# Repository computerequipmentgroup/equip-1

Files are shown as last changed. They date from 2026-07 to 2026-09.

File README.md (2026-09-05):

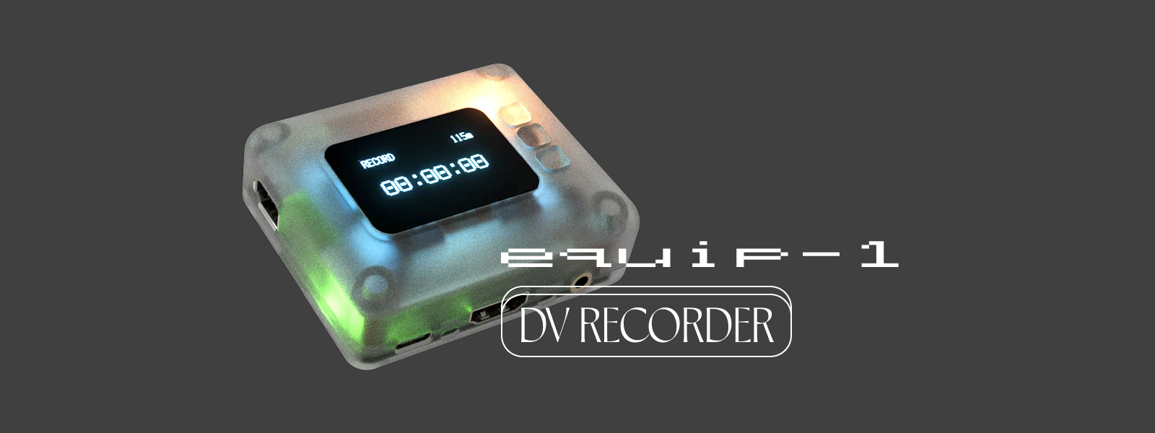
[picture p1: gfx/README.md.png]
Equip-1 DV Recorder


# Equip-1 ⚹ DV RECORDER

Equip-1 is an open-source, portable DV/HDV recorder for camcorders with FireWire/i.LINK/DV output. It is built around a Radxa ROCK 2F and a custom PCIe FireWire HAT, so you can mount it near a camera, power it from USB-C, press one button, and record tape footage directly to removable storage.

The project is for camera enthusiasts, videographers, film schools, archivists, and hardware/software contributors who want a modern, repairable path for capturing DV tapes without keeping an old laptop alive.

The [Firehat](https://github.com/computerequipmentgroup/firehat) is also available standalone. It works as a HAT for the ROCK 2F, Raspberry Pi 5, and other SBCs.

Website: <https://www.equip-1.c-e.group/>  
Community: [discord.gg/wpXmcb5mvK](https://discord.gg/wpXmcb5mvK)

## Features

- One-button DV/HDV capture from FireWire camcorders.
- On-device OLED/buttons UI + web based controls.
- Web UI controls for recording, video preview, file management and conversion settings.
- Full-quality `.mov`, `.dv`, `.avi`, or native HDV `.m2t` recordings.
- On-demand or automatic MP4 conversions for easy previewing and sharing.
- Optional MP4 deinterlacing for cleaner playback from interlaced DV sources.
- USB/SD capture storage handling, in-app updates, and HDMI preview support.

## Getting started

### 1. Download and flash a release image

The recommended way to get started is to use a prebuilt Equip-1 image from GitHub Releases.

1. Open the releases page: <https://github.com/computerequipmentgroup/equip-1/releases>
2. Download the latest image for your hardware; Equip-1 uses the Rock 2F image.
3. Install and open [balenaEtcher](https://etcher.balena.io/).
4. In Etcher, choose the Equip-1 image, choose your microSD card, then click **Flash**.
5. When flashing is complete, eject the card, insert it into Equip-1, and power the device over USB-C.

To build and flash an image from source instead:

```bash
./src/buildroot/scripts/build.sh
./src/buildroot/scripts/flash.sh
```

The default runtime settings are baked into the image from:

```text
src/buildroot/overlay/etc/equip1/equip-1.ini
```

On a running device, edit the live settings file at:

```text
/etc/equip1/equip-1.ini
```

### 2. Connect to Equip-1

Default device access:

| Setting | Default |
| --- | --- |
| Wi-Fi SSID | `Equip-1` |
| Wi-Fi password | `firesecret` |
| Dashboard | `http://10.42.0.1/` |
| API base | `http://10.42.0.1/api` |

Connect a phone or laptop to the Equip-1 Wi-Fi network, open the dashboard, attach a FireWire DV/HDV camera, and use the web UI or the device buttons to preview and record.

### 3. Prepare capture storage

Equip-1 records to `/data/captures` by default. At boot it prefers a non-root exFAT USB-A drive labelled `EQUIP1`; otherwise it falls back to the SD-card data partition. On a freshly flashed compressed image, first boot creates the missing SD-card recordings partition in the remaining free space, formats it as exFAT, labels it `EQUIP1`, and mounts it at `/data`.

Recommended capture storage format:

- filesystem: exFAT
- label: `EQUIP1`
- mount point on device: `/data`
- captures path: `/data/captures`

If automatic provisioning fails and the UI shows only rootfs-sized free space, create one exFAT partition labelled `EQUIP1` in the unallocated space after the flashed image partitions. Do not modify the boot/rootfs partitions and do not create two exFAT data partitions.

### 4. Record and export

Completed DV recordings are written as full-quality `.mov` captures by default, with settings for raw `.dv` or `.avi` containers. HDV sources still record as native `.m2t`. MP4 sidecars can be created on demand from settings, or automatically after each recording if auto-MP4 export is enabled.

MP4 quality presets:

| Setting | OLED label | Use |
| --- | --- | --- |
| `small` | `[28]` | Smallest files |
| `balanced` | `[23]` | Middle ground |
| `high` | `[18]` | Close to source for most DV material |
| `max` | `[14]` | Highest quality, larger and slower |

See [`src/docs/mp4-export.md`](src/docs/mp4-export.md) for the full export flow.

## Runtime settings

User-facing device settings live at `/etc/equip1/equip-1.ini`. The default file is staged from `src/buildroot/overlay/etc/equip1/equip-1.ini`, and matching `EQUIP1_*` environment variables can override INI values for development or one-off debugging.

Example:

```ini
[network]
ap_ssid = Equip-1
ap_password = firesecret

[recording]
capture_dir = /data/captures
storage_label = EQUIP1
recording_format = mov
auto_convert_mp4 = false
mp4_quality = high
mp4_deinterlace = true
auto_storage_switch = true

[hdmi]
enabled = true

[logging]
log_level = info
```

## Docs

The full source documentation lives in `src/docs/` and covers the runtime settings, capture pipeline, storage behavior, user interfaces, and Buildroot image. Start with the topic that matches what you are changing, then follow the linked references for lower-level implementation details.

- [`src/docs/runtime-settings.md`](src/docs/runtime-settings.md) — `/etc/equip1/equip-1.ini` sections, common keys, and environment overrides.
- [`src/docs/mp4-export.md`](src/docs/mp4-export.md) — MP4 sidecar export flow, OLED labels, and quality presets.
- [`src/docs/storage-captures-usb.md`](src/docs/storage-captures-usb.md) — capture storage, `/data/captures`, USB switching, and USB-C mass-storage mode.
- [`src/docs/buildroot-image.md`](src/docs/buildroot-image.md) — image build flow, rootfs overlay, init ordering, and runtime logs.
- [`src/docs/daemon-api.md`](src/docs/daemon-api.md) — daemon state model, commands, HTTP endpoints, streams, and WebSocket events.
- [`src/docs/dv-stream-recording-preview.md`](src/docs/dv-stream-recording-preview.md) — FireWire capture path, recording, browser preview, and HDMI/VLC output.
- [`src/docs/uis.md`](src/docs/uis.md) — OLED/buttons UI, browser dashboard, local designer, and static web build.
- [`src/docs/development-and-services.md`](src/docs/development-and-services.md) — local development workflows and Debian/Radxa service templates.
- [`src/docs/architecture.md`](src/docs/architecture.md) — how the daemon, shared stream, UIs, storage, and image overlay fit together.

## Hardware

- Radxa ROCK 2F (Rockchip RK3528A, quad-core ARM Cortex-A53, 2 GB RAM)
- [Firehat](https://github.com/computerequipmentgroup/firehat)
- MicroSD storage
- USB-C power input, 5 V
- HDMI output
- Wi-Fi 6, Bluetooth 5.4
- 2× USB 2.0 Type-A
- 60 mm × 70 mm × 25 mm, ~100 g

## Repository structure

This is an open-source hardware product repository. Editable product sources, generated manufacturing files, source code, and graphics assets are kept separate:

- `hw/` — electronics, mechanical design, manufacturing exports, and validation notes.
- `src/` — recorder daemon, OLED/web UIs, Buildroot image tooling, and development service templates.
- `gfx/` — renders, photos, product images, diagrams, screenshots, and logos.

Key source paths:

- `src/equip1d/` — FastAPI recorder daemon. Owns camera detection, `dvgrab`, deck control, capture storage, preview streaming, and recorder state.
- `src/uis/oled/` — 128×64 OLED/buttons frontend for on-device control.
- `src/uis/web/` — Nuxt static web dashboard for phone/laptop control over the local Equip-1 Wi-Fi AP.
- `src/buildroot/` — appliance image, kernel/boot fragments, rootfs overlay, init scripts, and flash/build tooling.
- `src/docs/` — architecture, runtime settings, Buildroot, storage, UI, and export notes.

## Development

Install Python dependencies:

```bash
python -m venv .venv
. .venv/bin/activate
pip install -r src/requirements.txt
```

Run the daemon locally:

```bash
PYTHONPATH=src python -m equip1d.main
```

Design OLED screens in a browser without hardware:

```bash
PYTHONPATH=src python -m uis.oled.designer
```

Open <http://127.0.0.1:8765>. The designer renders the real `src/uis/oled/screens.py` drawing code to a 128×64 PNG, with screen/scenario selectors, button simulation, and editable state JSON.

Build the web dashboard:

```bash
cd src/uis/web
npm install
npm run generate
```

The daemon serves `src/uis/web/.output/public` when it exists.

## Open source

Hardware is licensed under [CERN OHL-S](https://ohwr.org/cern_ohl_s_v2.txt). Software is licensed under GPL. Derivatives must be released under the same licenses.

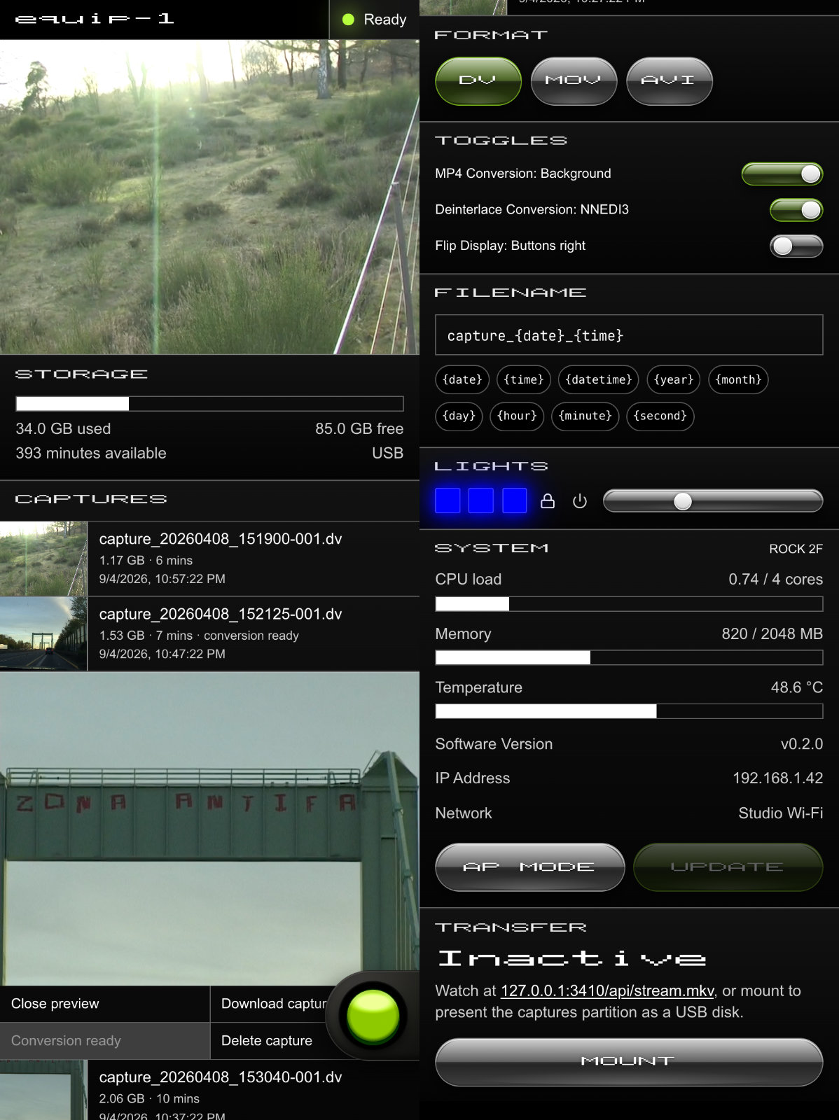
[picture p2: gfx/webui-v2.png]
Equip-1 web UI


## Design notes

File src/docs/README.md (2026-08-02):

# Source documentation

This directory is the source-code documentation hub for Equip-1 / Firehat.

## Start here

- [System architecture](architecture.md) — how the daemon, shared DV/HDV source, UIs, storage, and image overlay fit together.
- [Daemon and HTTP API](daemon-api.md) — `src/equip1d/`, state model, commands, streaming endpoints, and WebSocket events.
- [DV/HDV stream, recording, and preview](dv-stream-recording-preview.md) — the single shared FireWire capture path used by recording, browser preview, and HDMI/VLC output.
- [Storage, captures, and USB modes](storage-captures-usb.md) — `/data/captures`, removable storage switching, USB-C mass-storage mode, and capture metadata.
- [MP4 export options](mp4-export.md) — post-recording sidecar export flow, OLED labels, quality presets, and settings/API values.
- [User interfaces](uis.md) — OLED/buttons UI, browser dashboard, local designer, and static web build.
- [Runtime settings](runtime-settings.md) — `/etc/equip1/equip-1.ini` sections and important environment overrides.
- [Buildroot image](buildroot-image.md) — image build flow, rootfs overlay, init ordering, and package fragments.
- [Development and optional services](development-and-services.md) — local daemon/UI workflows and Debian/Radxa systemd templates.

## Hardware and Buildroot notes moved here

The former `src/buildroot/docs/` notes now live under [`buildroot/`](buildroot/):

- [Buildroot application integration](buildroot/equip1-app.md)
- [USB recording storage](buildroot/usb-recording-storage.md)
- [Enable I2C/SPI overlays](buildroot/enable-i2c-spi.md)
- [Enable PCIe power regulator overlay](buildroot/enable-pwr-en.md)

## Runtime path map

Source paths are staged into the appliance image like this:

| Repository path | Device path | Purpose |
| --- | --- | --- |
| `src/equip1d/` | `/opt/equip1/equip1d/` | FastAPI daemon and recorder backend |
| `src/uis/` | `/opt/equip1/uis/` | OLED UI and generated/static web dashboard source |
| `src/fonts/` | `/opt/equip1/fonts/` | OLED fonts |
| `src/requirements.txt` | `/opt/equip1/requirements.txt` | Python runtime requirements |
| `src/buildroot/overlay/` | `/` | BusyBox init scripts, settings, helpers, boot files |

The Buildroot build script stages these files before syncing the overlay into the builder VM.

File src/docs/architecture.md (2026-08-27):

# System architecture

Equip-1 is a small appliance around one central process: the `equip1d` daemon. The daemon owns camera discovery, the shared DV/HDV byte stream, recording state, storage state, preview streaming, and API events. The OLED UI and web dashboard are clients of that API.

```text
DV/HDV camera / FireWire
        │
        ▼
  dvgrab shared source       /data/captures
  src/equip1d/dvsource.py ───────┬── recording sink (.mov/.dv/.avi/.m2t files)
        │                        │
        ├── ffmpeg MJPEG ────────┼── GET /api/preview.mjpg
        └── ffmpeg MKV copy ─────┴── GET /api/stream.mkv

FastAPI daemon (src/equip1d/api.py, service.py)
        │
        ├── OLED UI (src/uis/oled) polls /api/state and posts commands
        ├── Web UI (src/uis/web) uses REST + /api/events WebSocket
        ├── BusyBox init scripts in src/buildroot/overlay/etc/init.d
        └── helper scripts in src/buildroot/overlay/usr/sbin and /opt/equip1/scripts
```

## Core principles

- **One FireWire owner:** `DvSource` starts one long-lived `dvgrab -format raw -` process when a camera is present. dvgrab/AV-C and first-byte stream detection classify the stream as raw DV or native HDV/MPEG-TS, and recording/preview consume that same byte stream instead of fighting for the camera.
- **Recording is priority:** preview subscribers use bounded drop-oldest queues. If a browser or HDMI stream stalls, preview glitches before recording is allowed to back up.
- **State is centralized:** `Equip1Daemon.snapshot()` returns a single `DaemonState` object. UIs should render from this state rather than duplicating hardware probes.
- **Device settings are INI-backed:** `/etc/equip1/equip-1.ini` is the persistent user-facing settings file. Environment variables still override it for development and debugging.
- **Image is overlay-first:** the Buildroot overlay contains the init scripts and helper binaries; `src/buildroot/scripts/build.sh` stages current app sources into `/opt/equip1` before the image build.

## Important source areas

| Path | Responsibility |
| --- | --- |
| `src/equip1d/service.py` | High-level daemon orchestration: modes, commands, monitor loop, event publishing |
| `src/equip1d/api.py` | FastAPI routes, WebSocket event stream, static web mount |
| `src/equip1d/dvsource.py` | Long-lived `dvgrab` process, DV/HDV stream detection, threaded pipe drain, recording sink, preview fan-out |
| `src/equip1d/preview.py` | `ffmpeg` MJPEG preview and Matroska live stream wrappers |
| `src/equip1d/storage.py` | Capture listing, safe path lookup, storage capacity, thumbnails |
| `src/uis/oled/` | On-device OLED/buttons/LED UI and browser-based OLED designer |
| `src/uis/web/` | Nuxt dashboard, mock mode, captures/system/stream controls |
| `src/buildroot/` | Buildroot configs, external packages, DTS overlays, rootfs overlay, build/flash scripts |
| `src/systemd/` and `src/scripts/` | Optional Debian/Radxa development service templates and helpers |

## Normal boot flow in the image

1. Kernel and device-tree overlays boot from `src/buildroot/overlay/boot/`.
2. BusyBox init runs `src/buildroot/overlay/etc/init.d/S*` scripts.
3. `S15data` prepares `/data` and `/data/captures` from USB storage or the SD fallback partition.
4. `S50network` starts access-point, client, or disabled Wi-Fi mode.
5. `S60equip1d` exports settings and starts the FastAPI daemon on port `80`.
6. `S61equip1-oled` starts the OLED/buttons UI against `http://127.0.0.1/api`.
7. `S62equip1-hdmi-preview` watches HDMI status and opens `/api/stream.mkv?takeover=1` when needed.
8. `S98equip1-log-export` mirrors selected logs from `/var/log/equip1/` to `/data/logs/`.

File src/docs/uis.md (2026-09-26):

# User interfaces

Equip-1 has two first-party user interfaces:

- an on-device OLED/buttons/LED UI in `src/uis/oled/`;
- a browser dashboard in `src/uis/web/`.

Both are API clients. They should not probe camera/storage hardware directly; they render daemon state from `/api/state` and send commands back to `equip1d`.

## OLED UI

Run locally:

```sh
PYTHONPATH=src python -m uis.oled
```

Important files:

| File | Purpose |
| --- | --- |
| `app.py` | Main loop, state polling, button navigation, command dispatch, LED state |
| `screens.py` | Screen renderers and per-screen button behavior |
| `api_client.py` | Minimal HTTP client for daemon state and commands |
| `display.py` | OLED display backend, font loading, mock display support |
| `input.py` | Buttons and buzzer backends, mock input support |
| `leds.py` | RGB LED SPI backend, boot marquee, status colors |
| `designer.py` | Browser-based OLED screen designer |

The OLED app polls `/api/state` at `ui.state_fetch_interval` and keeps a fallback offline state if the daemon is unreachable. While recording, it extrapolates the elapsed timer locally between state polls so a slow or missed poll does not make the visible timestamp skip seconds. If `state.power.available` is true, it also overlays a centered PiSugar battery percentage/icon in the header; otherwise the header is unchanged. When `ui.oled_rotate_180` is enabled, the app rotates the framebuffer and flips the up/down button mapping so navigation still follows the visible screen orientation. OLED startup and recovery can be slowed with `ui.oled_settle_delay`, `ui.oled_recover_base_delay`, and `ui.oled_recover_max_delay`; the Pi 5/PiSugar image sets a longer settle delay and lower OLED FPS because PiSugar and OLED share the header I2C bus.

### OLED screens

Current screen order in `OledApp`:

1. `RecordingScreen` — record/stop, elapsed time, storage minutes.
2. `NetworkScreen` — AP/client/offline network details.
3. `UsbTransferScreen` — USB-C mass-storage mode controls.
4. `StorageScreen` — device kind, capacity, manual USB/SD switching.

`BootScreen` is shown for the boot animation before normal navigation starts.

### OLED designer

The designer renders the real `screens.py` drawing code in a browser without hardware:

```sh
PYTHONPATH=src python -m uis.oled.designer
```

Open <http://127.0.0.1:8765>. Use it when changing layout, fonts, or button-driven states.

## Web dashboard

The web dashboard is a static Nuxt app. During image builds, `src/buildroot/scripts/build.sh` runs `npm run generate` and the daemon serves `.output/public` from `/`.

Development:

```sh
cd src/uis/web
npm install
npm run dev
```

Mock mode, useful without hardware or the daemon:

```sh
cd src/uis/web
npm run dev:mock
```

Production static build:

```sh
cd src/uis/web
npm run generate
```

Important files:

| File | Purpose |
| --- | --- |
| `pages/index.vue` | Main dashboard UI and controls |
| `composables/useEquip1State.ts` | REST/WebSocket state, commands, mock recorder model |
| `composables/useEquip1Captures.ts` | Capture list and download URLs |
| `composables/useEquip1System.ts` | System stats polling |
| `assets/main.css` | Dashboard styling and responsive layout |
| `nuxt.config.ts` | Static SPA config, public API/WS base paths, PWA-ish metadata |

## Web live updates

`useEquip1State` connects to `/api/events` and periodically resyncs as a safety net:

- state resync every 3 seconds;
- captures resync every 10 seconds;
- command calls refresh state after completion.

Mock mode simulates recording growth, capture completion, thumbnails, and basic command errors entirely in the browser.

## UI settings

Common settings live in `/etc/equip1/equip-1.ini` under `[ui]`, with environment overrides:

| Setting | Env override | Default |
| --- | --- | --- |
| `api_base` | `EQUIP1_API_BASE` | `http://127.0.0.1/api` in the Buildroot image |
| `api_timeout` | `EQUIP1_API_TIMEOUT` | `5.0` |
| `state_fetch_interval` | `EQUIP1_STATE_FETCH_INTERVAL` | `1.0` |
| `boot_duration_seconds` | `EQUIP1_BOOT_DURATION_SECONDS` | `3.0` |
| `boot_hold_seconds` | `EQUIP1_BOOT_HOLD_SECONDS` | `1.1` |
| `oled_fps` | `EQUIP1_OLED_FPS` | `8` (`2` in Pi 5/PiSugar image) |
| `oled_settle_delay` | `EQUIP1_OLED_SETTLE_DELAY` | `0` (`15` in Pi 5/PiSugar image) |
| `oled_recover_base_delay` | `EQUIP1_OLED_RECOVER_BASE_DELAY` | `1.0` (`2.0` in Pi 5/PiSugar image) |
| `oled_recover_max_delay` | `EQUIP1_OLED_RECOVER_MAX_DELAY` | `15.0` (`20.0` in Pi 5/PiSugar image) |
| `oled_rotate_180` | `EQUIP1_OLED_ROTATE_180` | `false` |
| `recording_format` (`[recording]`) | `EQUIP1_RECORDING_FORMAT` | `mov` |
| `pisugar_enabled` (`[power]`) | `EQUIP1_PISUGAR_ENABLED` | `true` |
| `pisugar_socket` (`[power]`) | `EQUIP1_PISUGAR_SOCKET` | `/tmp/pisugar-server.sock` |
| `pisugar_poll_interval` (`[power]`) | `EQUIP1_PISUGAR_POLL_INTERVAL` | `5` |
| `pisugar_timeout` (`[power]`) | `EQUIP1_PISUGAR_TIMEOUT` | `0.075` |

The web app uses Nuxt public runtime variables (`NUXT_PUBLIC_*`) for client-side API base, WebSocket base, mock mode, and performance logging.

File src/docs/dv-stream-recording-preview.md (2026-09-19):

# DV/HDV stream, recording, and preview

The capture path is built around `src/equip1d/dvsource.py`. It keeps one FireWire capture process alive, auto-detects whether the live bytes are raw DV or native HDV/MPEG-TS, and fans the resulting stream out to recording and preview consumers.

## Why there is one shared source

FireWire DV/HDV devices do not behave well when multiple processes compete for the camera. Older designs often stopped preview, started `dvgrab` for recording, then restarted preview later. That adds latency and can miss the first frames.

Current design:

1. When a camera is present, the daemon starts `dvgrab -buffers <n> -format raw -`.
2. dvgrab uses AV/C to switch to HDV/MPEG-TS output for native HDV sources; otherwise it emits raw DV.
3. A dedicated OS thread drains the stdout pipe with blocking reads and classifies the first bytes as `dv` or `hdv`.
4. Recording is toggled by opening or closing a file sink on the already-flowing bytes.
5. Preview subscribers receive copies through bounded queues.
6. If the camera disappears, `dvgrab` exits unexpectedly, the muxer/writer fails, no bytes reach the recording writer, or the output file stops growing while the timer is running, the recorder reports an error state.

## Recording path

Important files:

- `src/equip1d/dvsource.py` — owns the `dvgrab` process and the recording write thread.
- `src/equip1d/recorder.py` — records user intent and capture metadata.
- `src/equip1d/service.py` — validates camera/storage state, starts/stops recording, publishes events.

A start command does this:

1. Rejects the command if already recording or USB-C disk mode is active.
2. Probes for a camera.
3. Checks at least one minute of estimated free capture space.
4. Ensures the shared source is running and waits briefly for stream format detection.
5. Opens `capture_YYYYMMDD_HHMMSS.mov` by default for DV, or `.dv`/`.avi` when selected in settings; native HDV always records as `capture_YYYYMMDD_HHMMSS.m2t` in `/data/captures`. MOV/AVI are FFmpeg stream-copy containers, so the original DV essence is preserved. If the ROCK 2F clock is still unset and the stream is DV, the daemon first tries to use the DV camera datecode from the live stream for that timestamp.
6. Publishes the updated state, including `camera.format` and `recording.format`.

A stop command closes the recording sink and immediately publishes idle state plus the freshly closed capture list, so LEDs/UI do not wait on slower finalization. In the background the daemon reads the first raw DV frames for embedded camera recording date/time when applicable, stamps the capture file mtime when datecode is present, runs `sync`, republishes captures, then generates JPG thumbnails and republishes captures again.

## Preview path

`src/equip1d/preview.py` wraps `ffmpeg` around a `DvSource` subscription:

- `/api/preview.mjpg` transcodes DV or HDV to multipart MJPEG for browsers.
- `/api/stream.mkv` copies raw DV or HDV/MPEG-TS into a Matroska container for VLC and HDMI preview.

The two stream types share one busy lock. Only one preview/MKV consumer should be active at a time. `takeover=1` on `/api/stream.mkv` lets HDMI preempt a stale or browser-owned preview.

## Backpressure rules

Recording is the priority path:

- The `dvgrab` pipe is drained on a dedicated thread, not by the asyncio event loop.
- Preview queues are bounded and drop the oldest queued chunk if a consumer stalls.
- Recording has its own writer thread and queue.
- Browser or HDMI preview can glitch without blocking the FireWire read loop.

## DIF header normalization

Some camcorders emit DV DIF blocks that are playable but rejected by parts of `ffmpeg`/libavformat. `DvSource` can normalize the DIF block ID byte at 80-byte boundaries. This runs only after the stream has been classified as raw DV; HDV/MPEG-TS bytes are never normalized.

- Enabled by default: `EQUIP1_DV_NORMALIZE_DIF=1`
- Disable for debugging: `EQUIP1_DV_NORMALIZE_DIF=0`

## Useful tuning knobs

| Variable | Default | Purpose |
| --- | --- | --- |
| `EQUIP1_DV_BUFFERS` | `50` | `dvgrab -buffers` ring size |
| `EQUIP1_DV_PIPE_BYTES` | `1048576` | Target kernel pipe size between `dvgrab` and reader |
| `EQUIP1_DV_FORMAT_PROBE_BYTES` | `4096` | Accumulated bytes to sniff before defaulting an unrecognized stream to DV |
| `EQUIP1_DV_RECORD_QUEUE` | `2048` | Recording writer queue length |
| `EQUIP1_RECORDING_FIRST_BYTES_TIMEOUT` | `5.0` | Seconds after record start before failing if no bytes reach the writer or output file |
| `EQUIP1_RECORDING_STALL_TIMEOUT` | `8.0` | Seconds before failing if an active recording stops writing bytes or growing on disk |
| `EQUIP1_DV_PREVIEW_QUEUE` | `32` | Preview subscriber queue length |
| `EQUIP1_PREVIEW_FPS` | `25` | Idle browser preview FPS |
| `EQUIP1_PREVIEW_SIZE` | `720:540` | Idle browser preview size |
| `EQUIP1_PREVIEW_RECORDING_FPS` | `2` | Browser preview FPS while recording |
| `EQUIP1_PREVIEW_RECORDING_SIZE` | `480:360` | Browser preview size while recording |
| `EQUIP1_PREVIEW_STALE_SECONDS` | `12` | Age after which an active stream can be treated as stale |

Prefer changing preview FPS/size before changing DV queue sizes.

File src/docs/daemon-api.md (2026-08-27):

# Daemon and HTTP API

The daemon is the source of truth for recorder state and control. It is started with:

```sh
PYTHONPATH=src python -m equip1d.main
```

On the appliance image, `S60equip1d` runs the same module from `/opt/equip1`.

## Main modules

- `src/equip1d/main.py` — entrypoint, Uvicorn startup, optional captive portal redirect server; disabled by default so operating systems do not open captive-network assistants.
- `src/equip1d/api.py` — FastAPI routes, streaming responses, WebSocket endpoint, static web dashboard mount.
- `src/equip1d/service.py` — `Equip1Daemon`, command validation, monitor loop, state snapshots, event publishing.
- `src/equip1d/power.py` — optional PiSugar power-manager socket reader for battery status.
- `src/equip1d/models.py` — dataclass state model returned by `/api/state`.
- `src/equip1d/camera.py` and `deck.py` — FireWire camera detection and on-demand AV/C deck commands.
- `src/equip1d/settings.py` — shared INI settings loader/saver.

## Daemon modes

`state.mode` is one of:

| Mode | Meaning |
| --- | --- |
| `idle` | Camera detected, storage has room, ready to record |
| `no_camera` | No usable DV/HDV camera detected |
| `recording` | A capture file is currently being written |
| `storage_full` | Less than one minute of estimated capture capacity remains |
| `mounting` | `/data` is being mounted, remounted, or switched |
| `usb_transfer` | `/data` is exported over USB-C mass-storage mode |
| `converting` | One or more captures are being converted to MP4 |
| `error` | A command, monitor, recorder, storage, or USB operation failed |

`models.py` also reserves `booting` and `stopping` for UI/state compatibility. While `mounting` or `usb_transfer`, captures are hidden and live streaming is disabled.

## REST endpoints

| Method | Path | Purpose |
| --- | --- | --- |
| `GET` | `/api/state` | Full daemon state snapshot |
| `GET` | `/api/storage` | `state.storage` only |
| `GET` | `/api/system` | CPU, memory, model, and temperature stats |
| `GET` | `/api/network/wifi` | Current Wi-Fi setup/status summary |
| `GET` | `/api/network/wifi/scan` | Best-effort scan for visible SSIDs, including AP-mode scan via `iw ... ap-force` where supported |
| `POST` | `/api/network/wifi` | Save client Wi-Fi `ssid`/`password`, switch from AP to client mode, and restart networking |
| `POST` | `/api/network/ap` | Switch back to Equip-1 access-point mode and restart networking |
| `GET` | `/api/captures` | Capture files and thumbnail/download URLs |
| `GET` | `/api/captures/{name}/download` | Download a capture file by safe basename |
| `GET` | `/api/captures/{name}/thumbnail` | Download generated JPG thumbnail |
| `GET` | `/api/preview.mjpg` | Browser MJPEG preview stream |
| `GET` | `/api/stream.mkv` | Live DV or HDV copied into a Matroska stream for VLC/HDMI |
| `POST` | `/api/time` | Set device clock from browser time only if clock is unset |
| `POST` | `/api/settings/recording-format` | Set full-quality DV recording container to `mov`, `dv`, or `avi` |
| `POST` | `/api/settings/conversion` | Set automatic capture-to-MP4 mode (`off`, Blocking as `foreground`, or `background`), MP4 quality, and MP4 deinterlacing |
| `POST` | `/api/settings/auto-storage-switch` | Enable/disable idle USB/SD automatic switching |
| `POST` | `/api/settings/hdmi-preview` | Persist HDMI preview enabled/disabled for the preview watcher |
| `POST` | `/api/settings/oled-rotation` | Persist built-in OLED 180-degree rotation (`rotate_180` or `enabled`) |
| `POST` | `/api/settings/lights` | Set LED enabled/disabled state |
| `POST` | `/api/commands/start-recording` | Start recording to `/data/captures` |
| `POST` | `/api/commands/stop-recording` | Stop recording and schedule thumbnails |
| `POST` | `/api/commands/rescan-camera` | Publish a fresh state snapshot |
| `POST` | `/api/commands/deck-play` | Send AV/C play command with `dvcont` |
| `POST` | `/api/commands/deck-stop` | Send AV/C stop command |
| `POST` | `/api/commands/deck-rewind` | Send AV/C rewind command |
| `POST` | `/api/commands/deck-fast-forward` | Send AV/C fast-forward command |
| `POST` | `/api/commands/clear-error` | Clear current error and republish state |
| `POST` | `/api/commands/usb-storage-start` | Stop capture/preview and export `/data` over USB-C |
| `POST` | `/api/commands/usb-storage-stop` | Stop USB-C mass-storage mode and remount `/data` |
| `POST` | `/api/commands/storage-switch-usb` | Manually switch `/data` to USB-A storage |
| `POST` | `/api/commands/storage-switch-sd` | Manually switch `/data` back to SD fallback |
| `POST` | `/api/commands/convert-all-mp4` | Convert captures missing same-stem `.mp4` sidecars in the background |

Command failures are returned as HTTP `409` with a text `detail`. User errors such as invalid time payloads or Wi-Fi credentials are `400`; missing files are `404`.

The Wi-Fi setup flow is intentionally skippable: devices default to AP mode for direct dashboard control, but software update checks require the device itself to have upstream internet through client Wi-Fi/LAN. Dashboard URLs use the device IP address without an explicit port: `http://10.42.0.1` in AP mode, or the LAN IP shown by state/OLED in client mode. If client Wi-Fi fails to get an IP address, network startup falls back to AP mode.

`state.camera.format` is `"unknown"`, `"dv"`, or `"hdv"`. It starts as `"unknown"` after a camera appears and changes once the shared `dvgrab` stream emits enough bytes to classify the source. DV recordings default to `.mov`, with `.dv` and `.avi` selectable through settings. `.mov`/`.avi` are FFmpeg stream-copy containers, not transcoded MP4 exports. Native HDV/MPEG-TS still records as `.m2t`.

`state.power` is optional PiSugar battery status. When `pisugar-server` is reachable at `/tmp/pisugar-server.sock`, `state.power.available` is `true` and `battery_percent` is populated for the OLED header indicator. Non-PiSugar builds or missing batteries report `available=false`.

## WebSocket events

`WS /api/events` sends an initial `state`, an initial `captures`, then future daemon events:

```json
{ "type": "state", "state": { "mode": "idle" }, "server_sent_at": 1783720000.0 }
{ "type": "captures", "captures": [], "server_sent_at": 1783720001.0 }
```

The WebSocket also accepts settings messages from the web UI:

```json
{ "type": "set-light-color", "colors": [[0, 0, 255], [0, 0, 255], [0, 0, 255]] }
{ "type": "set-lights-enabled", "enabled": true }
{ "type": "set-lights-brightness", "brightness": 0.25 }
{ "type": "set-recording-format", "format": "mov" }
{ "type": "set-auto-convert-mp4", "mode": "background" }
{ "type": "set-mp4-quality", "quality": "high" }
{ "type": "set-mp4-deinterlace", "enabled": true }
```

Light, conversion, storage, HDMI, and OLED rotation settings are persisted through `Equip1Settings` into `/etc/equip1/equip-1.ini`. The OLED UI uses the REST settings endpoints.

## Static dashboard serving

At startup `api.py` mounts `EQUIP1_WEB_DIR` at `/` when it exists. The default is:

```text
src/uis/web/.output/public
```

The Buildroot build runs `npm run generate` and stages this output into `/opt/equip1/uis/web/.output/public`.

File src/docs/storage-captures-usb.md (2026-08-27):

# Storage, captures, and USB modes

Equip-1 records into `/data/captures`. The daemon does not need to know whether `/data` is backed by USB-A storage, SD fallback storage, or another mount; it uses `StorageManager` to inspect the active mount and list captures safely.

## Source files

- `src/equip1d/storage.py` — storage capacity snapshots, capture list, safe capture/thumbnail path lookup, thumbnail generation.
- `src/equip1d/service.py` — storage switch orchestration, USB-C disk-mode orchestration, capture event publishing.
- `src/buildroot/overlay/etc/init.d/S15data` — boot-time `/data` mount selection.
- `src/buildroot/overlay/usr/sbin/equip1-storage-switch` — runtime switch between USB-A storage and SD fallback.
- `src/buildroot/overlay/usr/sbin/equip1-usb-storage` — USB-C mass-storage gadget export for the active `/data` block device.

## `/data` mount selection

At boot, `S15data` creates `/data/captures` and chooses storage in this order:

1. A non-root exFAT partition labelled `EQUIP1`.
2. If no labelled partition exists, exactly one non-root exFAT partition.
3. SD/rootfs fallback partition.

See [buildroot/usb-recording-storage.md](buildroot/usb-recording-storage.md) for operator-level USB preparation and expected logs.

## Runtime storage switching

While idle, the daemon monitor loop can automatically switch storage:

- USB-A inserted: attempt switch to USB.
- Active USB-A removed: attempt switch back to SD fallback.
- Recording or USB-C transfer active: do not switch.

Manual API commands are also available:

```sh
curl -X POST http://127.0.0.1/api/commands/storage-switch-usb
curl -X POST http://127.0.0.1/api/commands/storage-switch-sd
```

The daemon stops preview and the shared DV/HDV source before switching so helper scripts can unmount `/data` safely. It refuses to switch while recording.

## USB-C mass-storage mode

USB-C transfer mode exports the block device currently backing `/data` to a host computer.

Start:

```sh
curl -X POST http://127.0.0.1/api/commands/usb-storage-start
```

Stop:

```sh
curl -X POST http://127.0.0.1/api/commands/usb-storage-stop
```

Before exporting, the daemon stops recording if needed, stops preview, stops the shared DV/HDV source, runs `sync`, and calls `/usr/sbin/equip1-usb-storage start`. During storage switches and USB-C start/stop remounts, `state.mode` is `mounting` so UIs can show a wait indicator. While `mounting` or `usb_transfer`, captures are hidden and live streaming is disabled.

## Capture entries

`GET /api/captures` returns rows like:

```json
{
  "name": "capture_20260710_121314.mov",
  "path": "/data/captures/capture_20260710_121314.mov",
  "size_bytes": 12345678,
  "modified_at": 1783685594.0,
  "download_url": "/api/captures/capture_20260710_121314.mov/download",
  "thumbnail_url": "/api/captures/capture_20260710_121314.mov/thumbnail"
}
```

Only regular files with capture extensions are listed: `.dv`, `.dif`, `.m2t`, `.mts`, `.ts`, `.avi`, `.mov`, `.mp4`, `.mkv`. Downloads and thumbnails are resolved by basename only to avoid path traversal.

## Thumbnails

After recording stops, the daemon immediately publishes the freshly closed capture list. Finalization then continues in the background: for raw DV captures, the daemon stamps the capture file mtime from embedded DV camera datecode when present, checking the common DV pack layouts (VAUX video date/time `0x62`/`0x63`, AAUX audio date/time `0x52`/`0x53`, and a subcode fallback). It then runs `sync`, republishes captures, generates `capture_...jpg` beside the capture file using `ffmpeg`, trying a few seek points and writing through a temporary file before replacing the final JPG, and republishes captures again. The web UI only surfaces capture cards whose thumbnails are ready, so a fresh recording appears complete.

## Capacity estimate

`storage.recording_minutes_available` uses a fixed estimate:

```text
216 MiB per minute of DV/HDV
```

This is conservative for DV25 and native HDV and is used to block recording when less than one minute remains.

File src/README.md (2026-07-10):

# Source

Runtime application, UIs, image build tooling, and development service templates for Equip-1 / Firehat.

Documentation starts in [`docs/`](docs/README.md). The old `buildroot/docs/` notes now live in [`docs/buildroot/`](docs/buildroot/README.md).

- `equip1d/` — recorder daemon and HTTP/WebSocket API
- `uis/oled/` — OLED/buttons frontend
- `uis/web/` — Nuxt web dashboard
- `buildroot/` — appliance image tooling and root filesystem overlay
- `docs/` — source architecture, daemon/API, UI, storage, settings, and Buildroot notes
- `systemd/` — optional Debian/Radxa development service templates
- `scripts/` — helper scripts used by development services
- `fonts/` — OLED UI fonts

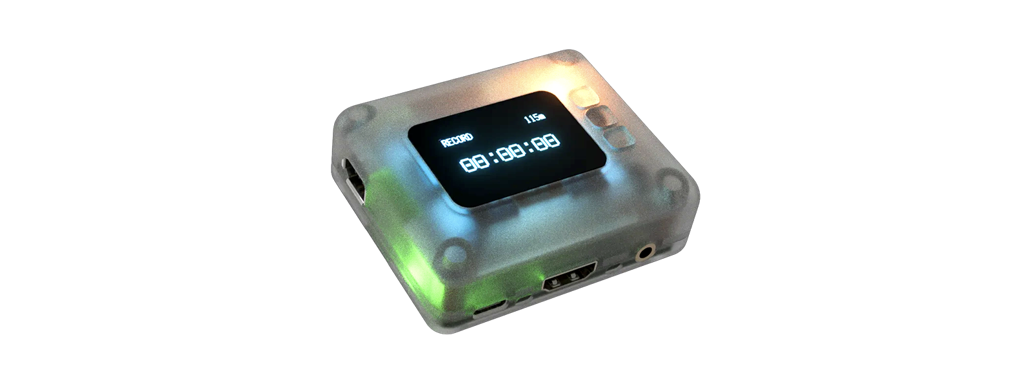
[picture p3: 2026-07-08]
gfx/equip-1.png

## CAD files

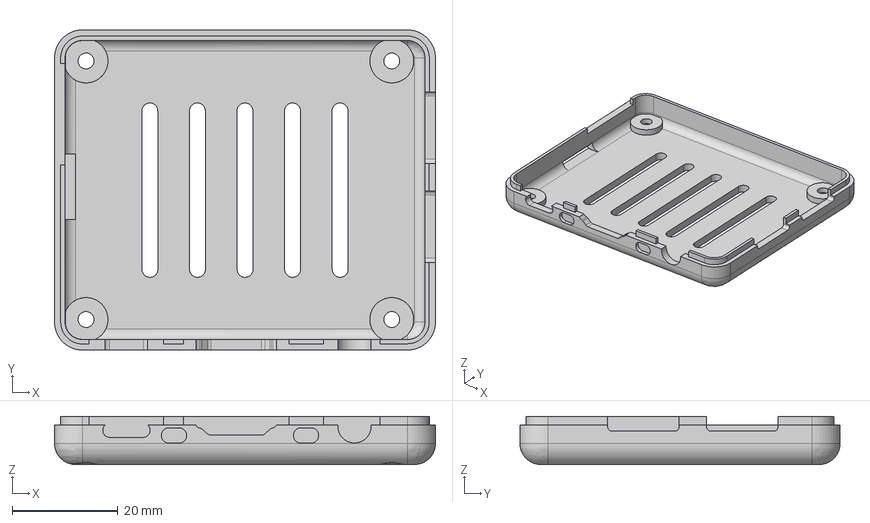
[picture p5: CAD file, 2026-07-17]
hw/shell-bot.step
72.1 x 60.6 x 9.10 mm

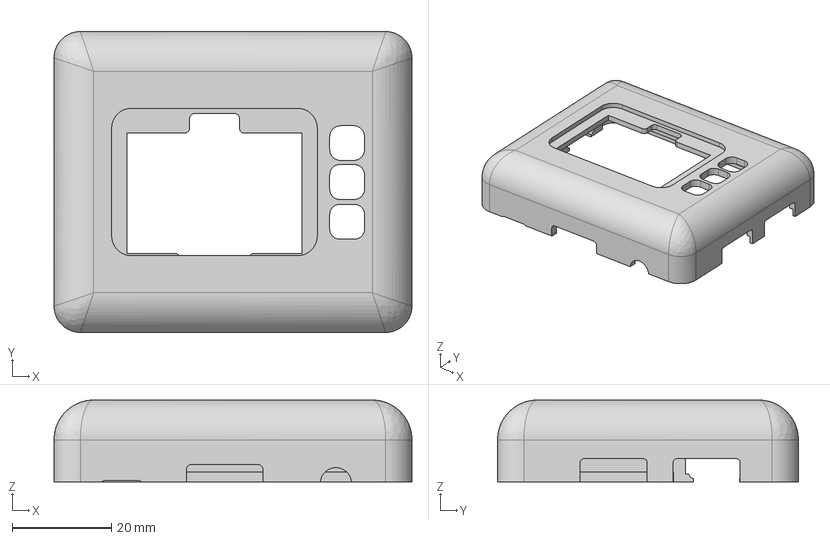
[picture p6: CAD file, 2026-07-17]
hw/shell-top.step
72.1 x 60.6 x 16.5 mm

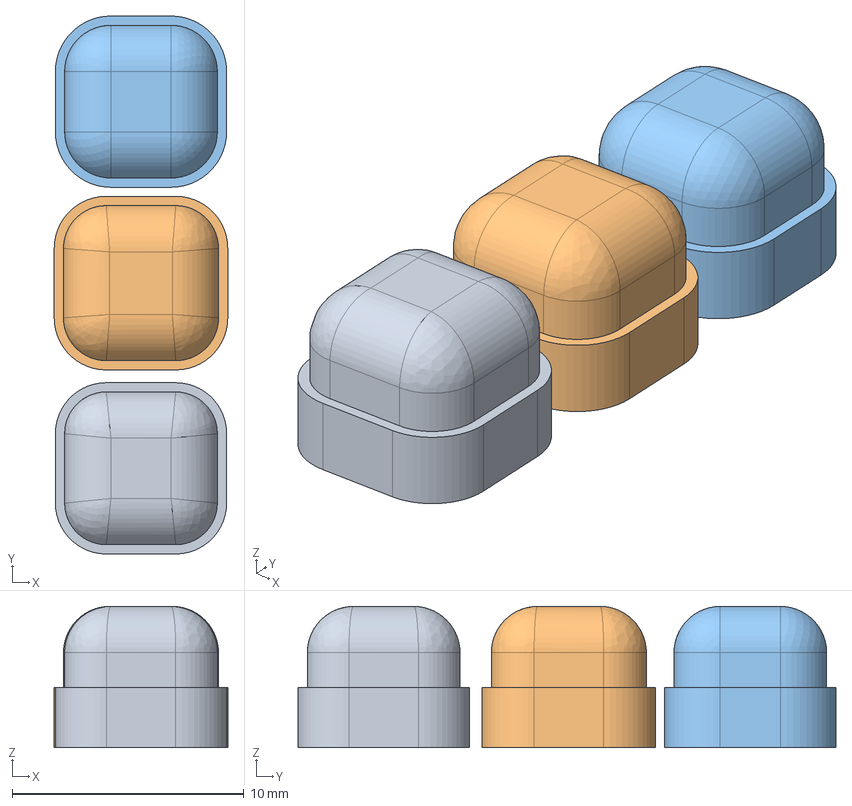
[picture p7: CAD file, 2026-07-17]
hw/buttons.step
7.50 x 23.2 x 6.10 mm

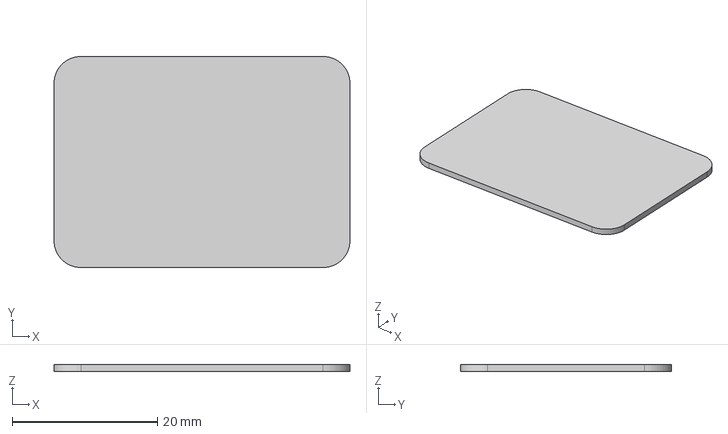
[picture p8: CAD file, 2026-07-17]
hw/screencover.step
40.8 x 29.1 x 1.00 mm

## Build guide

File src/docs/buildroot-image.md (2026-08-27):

# Buildroot image

Equip-1 is Buildroot-first. The image build combines Buildroot configs, a rootfs overlay, custom package recipes for the DV capture stack, device-tree overlays, and the current application source.

## Build and flash

```sh
./src/buildroot/scripts/build.sh
./src/buildroot/scripts/flash.sh
```

Raspberry Pi 5 + PiSugar 3 Plus image:

```sh
./src/buildroot/scripts/build.sh equip1_pi5_pisugar3plus_defconfig
xz -T0 -9 -c src/buildroot/output/sdcard.img > src/buildroot/output/equip-1-v0.1.0-pi5-pisugar3plus.img.xz
```

`build.sh` expects the `equip1-builder` VM workflow used by this repository. It builds the Nuxt dashboard on the host, stages app sources into the overlay, syncs Buildroot inputs to the VM, runs Buildroot, and writes artifacts under `src/buildroot/output/`.

## Web self-updates

The web dashboard can automatically update a running device from one release tag to the next, for example `v0.1.0` → `v0.1.1`, when the newer GitHub release includes an app update bundle. Build and attach the bundle with:

```sh
EQUIP1_VERSION_TAG=v0.1.1 ./src/scripts/package-update.sh
```

The script writes `dist/equip1-update.tar.gz`. Attach that asset to the GitHub release. Full `.img.xz` release assets are still for manual flashing and are intentionally ignored by the in-place updater.

## Important paths

| Path | Purpose |
| --- | --- |
| `src/buildroot/configs/equip1_defconfig` | Buildroot defconfig |
| `src/buildroot/configs/linux.config` | ROCK 2F kernel config fragment |
| `src/buildroot/configs/linux-pi5.config` | Raspberry Pi 5 kernel config fragment |
| `src/buildroot/configs/u-boot.config` | ROCK 2F U-Boot config fragment |
| `src/buildroot/configs/genimage.cfg` | ROCK 2F disk image partition layout |
| `src/buildroot/configs/genimage-pi5.cfg` | Raspberry Pi 5 disk image partition layout |
| `src/buildroot/dts/` | DTS overlays compiled into `/boot/overlay-user/*.dtbo` |
| `src/buildroot/external/` | Buildroot external tree for `dvgrab` and FireWire libraries |
| `src/buildroot/overlay/` | Root filesystem overlay copied into the target image |
| `src/buildroot/scripts/post-build.sh` | Target rootfs post-build adjustments |
| `src/buildroot/scripts/build.sh` | Host/VM orchestration script |
| `src/docs/buildroot/` | Hardware and image operation notes formerly in `src/buildroot/docs/` |

## Application staging

Before the Buildroot VM build, `build.sh` stages the current source tree into the overlay:

- `src/equip1d/` → `src/buildroot/overlay/opt/equip1/equip1d/`
- `src/uis/` → `src/buildroot/overlay/opt/equip1/uis/`
- `src/fonts/` → `src/buildroot/overlay/opt/equip1/fonts/`
- `src/requirements.txt` → `src/buildroot/overlay/opt/equip1/requirements.txt`

This means the repository source remains authoritative; do not edit staged copies under `src/buildroot/overlay/opt/equip1/` by hand unless you are intentionally changing generated/staged content.

## Init script order

BusyBox init runs scripts in lexical order:

| Script | Responsibility |
| --- | --- |
| `S10loopback` | Bring up loopback networking |
| `S15data` | Prepare `/data` from USB-A storage or SD fallback |
| `S20boot-debug` | Optional early debug breadcrumbs |
| `S50network` | Start Wi-Fi AP, client mode, or disabled networking; reports IP URLs and falls back to AP if client Wi-Fi fails |
| `S60equip1d` | Start FastAPI daemon on port `80` |
| `S61equip1-oled` | Start OLED/buttons UI |
| `S62equip1-hdmi-preview` | Start HDMI framebuffer preview watcher |
| `S98equip1-log-export` | Mirror logs from `/var/log/equip1/` into `/data/logs/` |
| `S99late-debug` | Optional late debug breadcrumbs |

## Build self-healing

`build.sh` applies a few targeted fixes before and between attempts:

- reasserts glibc toolchain settings if defconfig drifted to uClibc;
- removes an incompatible `CONFIG_DRM=n` override when Rockchip panel/DRM symbols fail;
- can force kernel, Python dependency, or ffmpeg cleanup on retry.

Environment knobs include `MAX_HEAL_ATTEMPTS`, `BUILD_JOBS`, `FORCE_KERNEL_CLEAN`, `FORCE_PYTHON_CLEAN`, `FORCE_PYTHON_DEPS`, and `FORCE_FFMPEG_CLEAN`.

## Runtime logs

Long-running service logs live under `/var/log/equip1/` so `/data` can be unmounted for storage switching and USB-C transfer mode. `equip1-export-logs` mirrors snapshots to `/data/logs/` when logging is not quiet.

Useful device commands:

```sh
/etc/init.d/S60equip1d restart
/etc/init.d/S61equip1-oled restart
/etc/init.d/S62equip1-hdmi-preview restart
tail -f /var/log/equip1/daemon.log
tail -f /var/log/equip1/oled.log
```

## Related docs

- [buildroot/equip1-app.md](buildroot/equip1-app.md)
- [buildroot/usb-recording-storage.md](buildroot/usb-recording-storage.md)
- [buildroot/enable-i2c-spi.md](buildroot/enable-i2c-spi.md)
- [buildroot/enable-pwr-en.md](buildroot/enable-pwr-en.md)

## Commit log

2026-07-04 feat: productionize Firehat/Equip-1 Buildroot image
    BREAKING: OLED screen navigation fixed — up/down buttons now match
    physical PCB labels (swap GPIO event direction).
    Highlights:
    - USB mass-storage TRANSFER mode: gadget/configfs, exclusive partition
    export, async start avoids OLED timeout, 'See SD log' error feedback
    - Host AP mode: hostapd/dnsmasq, SSID Firehat, captive portal with
    DHCP opt 114 + port-80 redirect for iOS/macOS auto-pop-up
    - RGB LED boot marquee: SK6812-EC20 (GRB, 800 kHz NRZ) via SPI0 MOSI,
    3.2 MHz 4-bit encoding, rainbow ping-pong at 25% brightness
    - OLED screen carousel reordered: RECORD->NETWORK->TRANSFER->DECK->STORAGE
    - Boot breadcrumbs always written to /var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
2026-07-05 feat: productionize web UI, fix DV thumbnails, live capture list
    Web UI
    - Remove mock/dev-only mode; the UI always talks to the real /api daemon
    and WebSocket. Drop the deleted captures/deck routes.
    - Live captures: the daemon pushes capture-list updates over the WebSocket,
    so new recordings appear without a reload, and only once their thumbnail
    has finished rendering.
    - Keep the real frame aspect ratio for thumbnails; long filenames/dates now
    truncate instead of pushing the row off-screen; thumbnail + download arrow
    always stay visible.
    - Native-app feel: no double-tap zoom / 300ms delay / tap flash / scroll
    bounce (pinch-zoom kept); standalone PWA meta tags.
    - Fix the danger bu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
2026-07-05 feat: live MJPEG preview, system stats, PWA, and storage reliability fixes
    Backend (firehatd):
    - Add on-demand MJPEG live preview (/api/preview.mjpg). Idle preview reads
    the FireWire bus via dvgrab and pipes raw DV through ffmpeg; during a
    recording the preview follows the growing capture file instead, so dvgrab
    stays the only reader/writer on the bus.
    - Add /api/system stats endpoint (CPU load, memory, SoC temperature).
    - Rework recorder into RecordingTracker: larger dvgrab buffers, SIGINT-first
    shutdown escalating to TERM/KILL, and an fs sync on stop so captures are
    flushed to the exFAT card.
    - Stop polling deck status/timecode every second. The dvcont probe ran AV/C
    transactio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
2026-07-05 chore: remove unused dvsource module
    DvSource was an experimental single-claim FireWire fan-out source that was
    never imported; the live preview uses MjpegPreview instead.
2026-07-05 feat: OLED status LED reflects capture state
    Light the third RGB LED to signal capture readiness at a glance:
    green when a camera is detected and ready, red while recording, and
    purple on the game screen. The LED is driven every frame after boot
    from the daemon state and the active screen.
2026-07-06 feat: LED test screen and all-LED status colors
    Add a prototyping LedTestScreen that cycles the RGB LEDs through a wide
    palette at fixed opacity, shows the current RGBA on the OLED, and appends
    the selected value to a file on Select.
    Drive all LEDs (not just a status index) with the exact emitted RGB
    value, add a dim no-camera state, and expose set_all for the test screen.
2026-07-06 feat: single shared DV source for instant recording
    Own the FireWire DV device with one long-lived dvgrab (DvSource) that
    tees raw DV to a recording file sink and to preview subscribers, instead
    of handing the device between preview and recorder. Recording now starts
    on the already-flowing stream (~0.2ms) with no preview stop / device
    re-acquisition delay.
    - dvsource.py: shared dvgrab reader drained on a dedicated OS thread so
    event-loop load can't starve capture; recording via its own writer
    thread + queue; bounded drop-oldest preview fan-out marshalled to the
    loop. -buffers 50 and enlarged pipe (F_SETPIPE_SZ) to avoid underruns.
    - recorder.py: thin state holder that toggles the reco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
2026-07-07 more games + led tests
2026-07-08 feat: add shared device settings
2026-07-08 feat: add HDMI framebuffer preview
2026-07-08 Improve Equip-1 boot diagnostics
    Rename device logs with an equip1 prefix and mirror key daemon/OLED/HDMI diagnostics onto /data for SD-card inspection.
    Enable perf logging via config/env truthy values and add OLED startup breadcrumbs for field debugging.
    Clean stale Firehat-era files during post-build and make overlay sync delete removed paths while preserving installed Python deps.
2026-07-08 Tune OLED buttons and remove power commands
2026-07-13 Debounce OLED buttons
2026-07-17 added step files
    [buttons.step, screencover.step, shell-bot.step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]
2026-08-02 feat: add MP4 export and OLED device settings
2026-08-09 Add PiSugar battery indicator
    Adds optional PiSugar power-manager battery status via the pisugar-server socket and renders the OLED battery percentage/icon when available.\n\nReferences https://github.com/computerequipmentgroup/f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
2026-08-09 Add Pi 5 PiSugar image target
    Adds a Raspberry Pi 5 Buildroot target for Equip-1 with PiSugar 3 Plus power-manager support staged from the upstream PiSugar release tarball.\n\nBuild artifact: equip-1-v0.1.0-pi5-pisugar3plus.img.xz
2026-08-12 Add camera compatibility issue template
2026-08-27 feat: improve device update and network UX
2026-08-29 Fix SD provisioning on compressed images
    Repair compressed-image GPTs on first boot, install sgdisk in Buildroot images, and fix S15data's parted -m free-space parser so oversized cards get an EQUIP1 recordings partition.
    Also isolate Rock 2F and Pi 5 Buildroot outputs to avoid stale cross-board kernel/module artifacts.
2026-09-04 Tighten release image instructions
